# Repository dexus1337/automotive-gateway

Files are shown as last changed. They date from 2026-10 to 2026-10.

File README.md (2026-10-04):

# Automotive Gateway: Multi-Bus ECU Interface, MitM Filter & Telemetry Board


[]()
[]()
[]()

An automotive-grade, multi-protocol vehicle network interface, Man-in-the-Middle (MitM) filter, and wireless telemetry gateway. Rather than focusing on CAN alone, this board provides full hardware integration for **all three common automotive ECU communication methods**:
1. **High-Speed CAN (HS-CAN / CAN FD)**
2. **Fault-Tolerant Low-Speed CAN (FT-CAN)**
3. **K-Line / LIN (ISO 9141-2 / ISO 14230 / LIN 2.x)**

All three protocols are driven by two dedicated 32-bit ARM Cortex-M4 microcontrollers and an ESP32 wireless co-processor, featuring dual isolated channels per protocol.

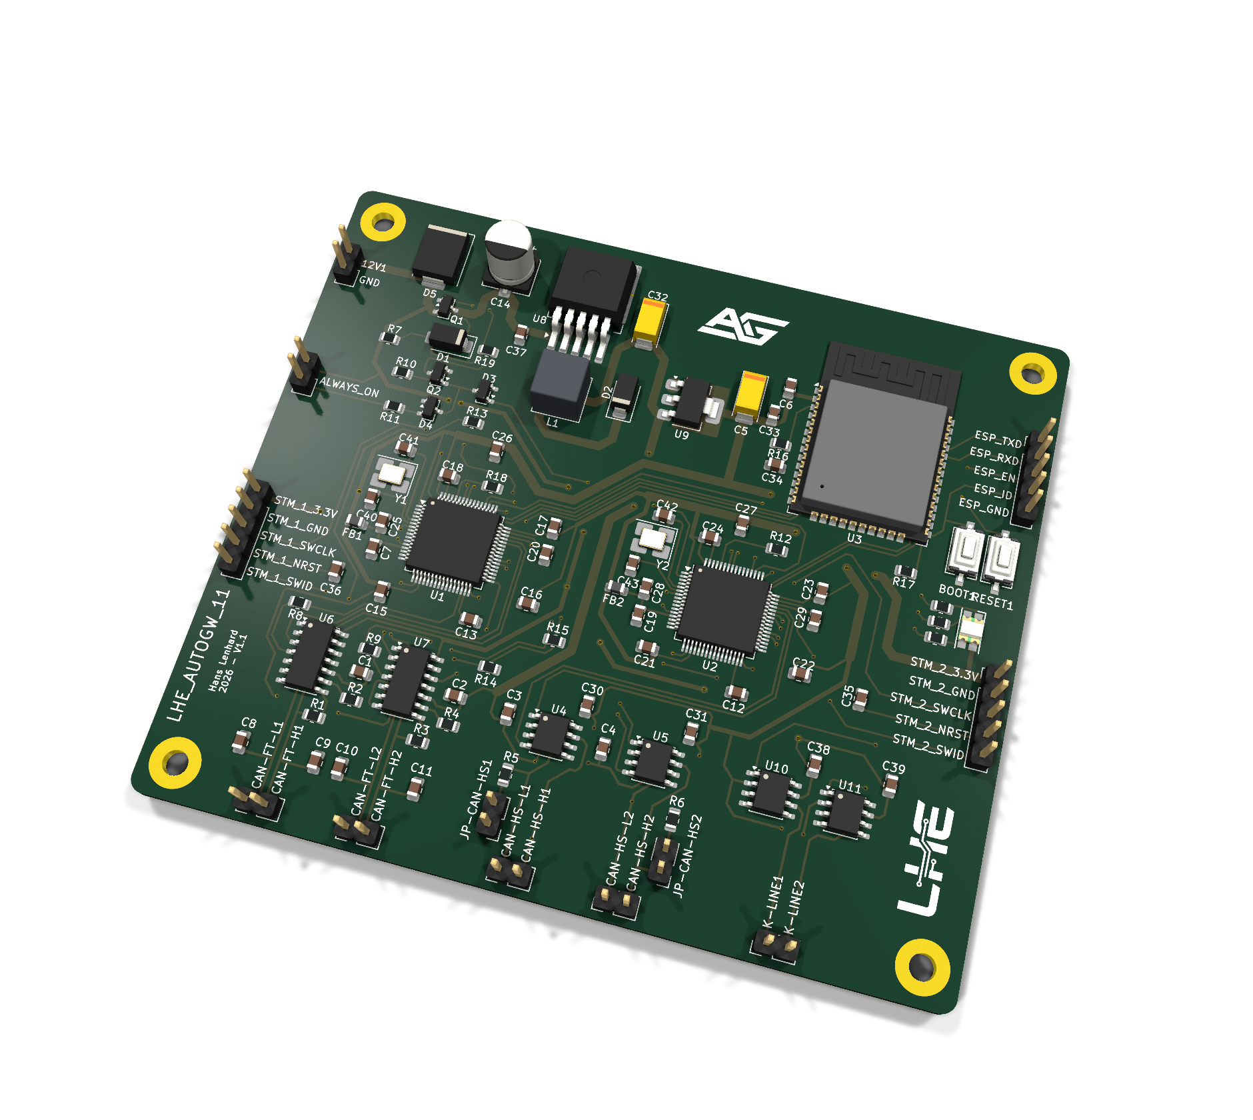
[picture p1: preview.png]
Automotive Multi-Bus Gateway PCB Preview


---

## 📑 Table of Contents

- [Overview](#-overview)
- [Operating Modes: Normal vs. MitM](#-operating-modes-normal-vs-mitm)
- [Power Management & Auto-Wake Architecture](#-power-management--auto-wake-architecture)
- [Key Features](#-key-features)
- [System Architecture](#-system-architecture)
- [Hardware & Functional Zones](#-hardware--functional-zones)
- [Pinout & Interface Definitions](#-pinout--interface-definitions)
- [Jumper Configuration Guide](#-jumper-configuration-guide)
- [Bill of Materials (BOM) Summary](#-bill-of-materials-bom-summary)
- [PCB Layout & Physical Specifications](#-pcb-layout--physical-specifications)
- [Getting Started & Flashing Guide](#-getting-started--flashing-guide)
- [Hardware Attribution](#-hardware-attribution)

---

## 🛠 Overview

Modern vehicle architectures rely on three primary communication standards to interconnect Electronic Control Units (ECUs) across various vehicle domains:
- **High-Speed CAN (HS-CAN / CAN FD)**: Up to 1 Mbps (CAN FD capable up to 5 Mbps) for latency-critical powertrain, drivetrain, braking, ABS, and chassis control.
- **Fault-Tolerant Low-Speed CAN (FT-CAN)**: Up to 125 kbps for robust body control, doors, lighting, climate (HVAC), and convenience systems, featuring automatic single-wire fallback upon bus faults.
- **K-Line / LIN (ISO 9141-2 / ISO 14230 / LIN 2.x)**: Bidirectional single-wire 12V automotive bus (up to 20 kbaud) universally used for OBD-II legacy diagnostics, ECU bench reflashing, instrumentation, and LIN sub-busses.

The **Automotive Gateway** provides a unified hardware platform equipped with dedicated transceivers for all three physical layers. It eliminates the need for separate diagnostic interfaces or multiple conversion dongles, serving as a comprehensive tool for active multi-bus communication, real-time message filtering, frame modification, diagnostic proxying, and wireless telemetry streaming via Wi-Fi and Bluetooth BLE.

---

## ⚙️ Operating Modes: Normal vs. MitM

The board features dual physical transceiver channels per communication method (Channel 1 and Channel 2), supporting two primary operating modes:

```
─────────────────────────────────────────────────────────────────────────────────────────────
 Mode 1: Normal Mode (Standalone Additional ECU / Gateway)
 [ Vehicle Network ] ◄──► ( Channel 1 ) ◄──► [ Dual-STM32 + ESP32 ] (Reads & Sends on Busses)

 Mode 2: In-line Man-in-the-Middle Mode (MitM Filter / Message Modification)
 [ Vehicle Network ] ◄──► ( Channel 1 ) ◄──► [ Real-Time Filter ] ◄──► ( Channel 2 ) ◄──► [ Target ECU ]
─────────────────────────────────────────────────────────────────────────────────────────────
```

### 1. Normal Mode (Standalone ECU)
> [!NOTE]
> **There is no listen-only mode.** In Normal Mode, the Automotive Gateway acts as an active, standalone, additional ECU on the vehicle networks.

- **Bi-directional Bus Access**: The gateway actively reads incoming data and transmits outgoing messages on the connected vehicle busses across all three supported physical interfaces (HS-CAN, FT-CAN, and K-Line/LIN).
- **Core Functions**:
  - Functions as an additional standalone ECU node directly participating on the network.
  - Broadcasts custom telemetry, control frames, or simulated sensor messages onto the bus.
  - Sends diagnostic requests (OBD-II, UDS / ISO 14229, KWP2000 / ISO 14230) to other vehicle ECUs and receives responses.
  - Acts as a bi-directional wireless gateway, streaming live multi-bus metrics and receiving remote commands over Wi-Fi (WebSockets, MQTT, REST) or Bluetooth LE.
- **Bus Connectivity**: Connects to the vehicle network via Channel 1 (`CAN-HS1`, `CAN-FT1`, and/or `K-LINE1 Pin 1`). Channel 2 can interface with a second independent vehicle bus, an auxiliary bench network, or remain unpopulated.

### 2. Man-in-the-Middle (MitM) Mode (In-line Filter & Message Modification)
- **Operation**: The gateway is inserted physically in-line between the vehicle wiring harness and a specific target Electronic Control Unit (ECU).
  - **Channel 1 (Network side)**: Connected to the main vehicle bus (`CAN-HS1`, `CAN-FT1`, or `K-LINE1 Pin 1`).
  - **Channel 2 (ECU side)**: Connected directly to the target ECU (`CAN-HS2`, `CAN-FT2`, or `K-LINE1 Pin 2`).
- **Core Functions**:
  - **Message Filtering**: Intercepts bidirectional communications in real time with sub-millisecond determinism to selectively filter out, block, or suppress unwanted messages, diagnostic requests, or forbidden IDs.
  - **Message Modification**: Inspects packets on the fly and modifies payload bytes, alters sensor values (e.g., vehicle speed, odometer, torque parameters), remaps frame IDs, recalculates CRCs/checksums, and retransmits them downstream.
  - **ECU Bench Testing & Security**: Allows fuzzing, spoofing responses, and security validation of a targeted ECU without injecting malformed or test frames into the rest of the vehicle.

---

## ⚡ Power Management & Auto-Wake Architecture

The board features an intelligent automotive power supply designed for both permanent vehicle installation and portable diagnostic use:

```
                        +12V Battery Input (12V1 Pin 1)
                                      │
                         [ D5: SMCJ24CA 24V TVS ]
                                      │
                         [ Q1: AO3401A P-MOSFET ]
                                      │ (12V_Switched)
                                      ▼
                        [ U8: LM2596S-5 Buck Conv ] ──► +5V Rail
                                      │
                        [ U9: AMS1117-3.3 LDO ]    ──► +3.3V Logic Rail
```

### Intelligent Sleep & Auto-Wake Circuit
To prevent 12V battery drain when permanently installed in a vehicle, the module features an ultra-low quiescent sleep circuit:
1. **Sleep State**: The high-side P-channel MOSFET (`Q1`) cuts +12V power to the buck converter (`U8`), completely disabling the 5V and 3.3V rails. The microcontrollers and ESP32 consume **zero current**.
2. **Wake-up Trigger**: The Fault-Tolerant CAN transceiver (`U6`, NXP TJA1055T) remains powered directly from the protected 12V battery rail in ultra-low quiescent standby mode. Upon detecting bus activity on FT-CAN Channel 1, `U6` asserts its `INH` pin HIGH, pulling the gate of N-channel MOSFET `Q2` high via dual Schottky diode `D4`.
3. **Power Latch (Keep-Alive)**: `Q2` activates, pulling `Q1`'s gate low to turn ON the system power rails. Once booted, MCU 1 (`U1`) and MCU 2 (`U2`) assert their respective keep-alive GPIOs (`PC13` via `D3`) to latch power continuously.
4. **Controlled Shutdown**: When vehicle network traffic ceases, the firmware prepares for safe shutdown and de-asserts `PC13`, allowing the board to return to sleep.
5. **Always-On Override (`J3`)**: Installing a jumper on header `J3` (`JP_ALWAYS_ON`) bypasses the auto-wake logic and holds the board permanently powered whenever +12V is present.

---

## ✨ Key Features

- **Dual ARM Cortex-M4 Processing Core**:
  - Two dedicated **STM32F405RGTx** microcontrollers running at **168 MHz** (1 MB Flash, 192 KB SRAM each).
  - **MCU 1 (`U1`)**: Dedicated Low-Speed Fault-Tolerant CAN controller (`CAN1` & `CAN2`).
  - **MCU 2 (`U2`)**: Dedicated High-Speed CAN (`CAN1` & `CAN2`) and Dual K-Line controller (`USART1` & `USART6`).
- **Direct High-Speed Inter-MCU Link**:
  - Dedicated hardware UART bus connecting MCU 1 and MCU 2 (`PC10` / `PC11`) for deterministic cross-bus message passing without co-processor latency.
- **All 3 Common Automotive ECU Physical Layers Supported (Dual Channels Each)**:
  - **High-Speed CAN (HS-CAN / CAN FD)**: 2× NXP `TJA1044GT-3` transceivers (ISO 11898-2:2016, CAN FD ready up to 5 Mbps) with switchable 120 Ω bus termination.
  - **Fault-Tolerant Low-Speed CAN (FT-CAN)**: 2× NXP `TJA1055T/3` transceivers (ISO 11898-3, up to 125 kbps) with single-wire fallback and automatic wake-up signaling.
  - **Dual K-Line / LIN (ISO 9141-2 / ISO 14230 / LIN 2.x)**: 2× NXP `TJA1021xT` transceivers (LIN 2.2A / SAE J2602) supporting OBD-II and KWP2000 diagnostic lines up to 20 kbaud.
- **High-Precision External Quartz Clocking (HSE)**:
  - Dedicated 8.000 MHz SMD-3225 4-pin quartz crystals (`Y1`, `Y2`) with 15 pF C0G load capacitors (`C40`–`C43`) for both STM32F405 MCUs.
  - Automotive-grade $\pm 10\,\text{ppm}$ clock accuracy, eliminating internal RC oscillator frequency drift across automotive temperature ranges.
  - **Zero-Error Baud Rate Timing**: Derives an exact 42 MHz APB1 peripheral clock, achieving $0.000\%$ timing error for the critical **83.3333 kBd** Fault-Tolerant CAN standard ($\text{BRP}=28$, $18\,T_q$, $83.33\%$ sample point) as well as exact bit rates for 100k, 125k, 250k, 500k, and 1 MBd HS-CAN / CAN FD.
- **Wireless Telemetry Co-Processor**:
  - **ESP32-WROOM-32UE** module with 2.4 GHz Wi-Fi (802.11 b/g/n) and Bluetooth v4.2 BR/EDR & BLE.
  - Integrated U.FL external antenna connector for high-gain antenna placement inside vehicle dashboards or engine bays.
  - Dual independent high-speed UART links connecting to MCU 1 and MCU 2.
- **User Interface & Diagnostic Feedback**:
  - Onboard RGB Status LED (`D6`, SMD 1210) driven by ESP32 GPIOs for mode, packet activity, and error signaling.
  - Tactile push buttons for ESP32 hardware `RESET` and `BOOT` (GPIO0).
- **Automotive Protection & Regulation**:
  - Automotive transient voltage suppressor (`D5`, SMCJ24CA bidirectional TVS).
  - P-channel MOSFET (`Q1`, AO3401A) reverse polarity and high-side power switching.
  - 12V Zener (`D1`, MMSZ12T1G) Vgs gate overvoltage clamp.
  - High-efficiency switching buck regulator (`U8`, LM2596S-5, 3A capacity).
  - Low-dropout linear regulator (`U9`, AMS1117-3.3, 1A capacity).
  - Ferrite bead filtering (`FB1`, `FB2`) on analog power supplies (`VDDA`).

---

## 📐 System Architecture

```
                                  +12V AUTOMOTIVE BATTERY (12V1)
                                                │
                          ┌─────────────────────┴─────────────────────┐
                          ▼                                           ▼
             [ SMCJ24CA 24V TVS Clamp ]                  [ AO3401A P-MOSFET Switch ]
                          │                                           │ (12V_Switched)
                          │                                           ▼
                          │                              [ LM2596S-5 Buck Regulator ] ──► +5V Rail
                          │                                           │
                          │                              [ AMS1117-3.3 LDO Regulator] ──► +3.3V Rail
                          │                                           │
         ┌────────────────┴───────────────────────────────────────────┴────────────────────────┐
         │                                                            │                        │
         ▼                                                            ▼                        ▼
┌───────────────────────────────┐               ┌───────────────────────────────┐   ┌──────────────────────┐
│      STM32F405 #1 (MCU 1)     │               │      STM32F405 #2 (MCU 2)     │   │   ESP32-WROOM-32UE   │
│   Low-Speed Fault-Tolerant    │◄─────────────►│     High-Speed CAN & K-Line   │   │   Wireless Gateway   │
│   CAN Controller (168 MHz)    │  Direct UART  │     Controller (168 MHz)      │   │   (Wi-Fi / BT / BLE) │
└──────┬─────────────────┬──────┘   (PC10/PC11) └──────┬─────────────────┬──────┘   └───────┬──────┬───────┘
       │ (CAN1)          │ (CAN2)                      │ (CAN1)          │ (CAN2)           │      │
       ▼                 ▼                             ▼                 ▼                  │      │
 ┌───────────┐     ┌───────────┐                 ┌───────────┐     ┌───────────┐            │      │
 │  TJA1055T │     │  TJA1055T │                 │ TJA1044GT │     │ TJA1044GT │      UART1 │      │ UART2
 │ (FT-CAN1) │     │ (FT-CAN2) │                 │ (HS-CAN1) │     │ (HS-CAN2) │   (PA2/PA3)│      │(PA2/PA3)
 └─────┬─────┘     └─────┬─────┘                 └─────┬─────┘     └─────┬─────┘            │      │
       │                 │                             │                 │                  │      │
       ▼                 ▼                             ▼                 ▼                  │      │
 [  CAN-FT1  ]     [  CAN-FT2  ]                 [  CAN-HS1  ]     [  CAN-HS2  ]            ▼      ▼
 (Channel 1)       (Channel 2)                   (Channel 1)       (Channel 2)          [ Independent ]
  Normal / MitM     Normal / MitM                 Normal / MitM     Normal / MitM       [ UART Links  ]
                                                       │                 │                     │
                                                 ┌─────┴─────┐     ┌─────┴─────┐               ▼
                                                 │JP-CAN-HS1 │     │JP-CAN-HS2 │        [ RGB LED (D6) ]
                                                 │(120Ω Term)│     │(120Ω Term)│        [ GPIO25/26/27 ]
                                                 └───────────┘     └───────────┘
                                                
                                                [ MCU 2 UARTs (USART6 / USART1) ]
                                                               │
                                                   ┌───────────┴───────────┐
                                                   ▼                       ▼
                                             ┌───────────┐           ┌───────────┐
                                             │ TJA1021xT │           │ TJA1021xT │
                                             │ (K-Line 1)│           │ (K-Line 2)│
                                             └─────┬─────┘           └─────┬─────┘
                                                   │                       │
                                                   ▼                       ▼
                                             [        K-LINE1 Header       ]
                                             [  Pin 1: Ch 1  |  Pin 2: Ch 2]
                                             [         Normal / MitM       ]
```

---

## 🔍 Hardware & Functional Zones

### Zone 1: Power Regulation, Switching & Protection
- **Power Input**: Connector `12V1` (Pin 1: `+12V_Protected`, Pin 2: `GND`).
- **Protection**:
  - `D5` (`SMCJ24CA`): Bidirectional TVS diode clamps automotive load-dump surges.
  - `Q1` (`AO3401A`): P-channel MOSFET provides high-side switching and reverse-polarity protection.
  - `D1` (`MMSZ12T1G`): 12V Zener clamps gate-source voltage ($V_{GS}$) of `Q1`.
  - `D2` (`SS34`): 3A 40V Schottky barrier rectifier for the buck switching regulator.
- **Power Switching Logic**:
  - `Q2` (`2N7002`): N-channel MOSFET drives `Q1`'s gate low to enable system power.
  - `D4` (`BAT54C`): Dual diode ORs the auto-wake signal from `U6` (`INH`) and `J3` (`ALWAYS_ON`).
  - `D3` (`BAT54C`): Dual diode ORs keep-alive latch signals from MCU 1 (`U1 PC13`) and MCU 2 (`U2 PC13`).
- **Regulators**:
  - `U8` (`LM2596S-5`): High-efficiency 5V 3A step-down switching regulator.
  - `U9` (`AMS1117-3.3`): 3.3V 1A linear LDO regulator for logic and radio power.

### Zone 2: MCU #1 – Low-Speed Fault-Tolerant CAN Core
- **Microcontroller**: `U1` (`STM32F405RGTx` LQFP-64, ARM Cortex-M4 @ 168 MHz).
- **External Clock Source**: `Y1` (8.000 MHz SMD-3225 4-pin crystal on `PH0-OSC_IN` [Pin 5] and `PH1-OSC_OUT` [Pin 6]) with 15 pF load capacitors `C40` & `C41`.
- **Transceivers**: `U6` & `U7` (`NXP TJA1055T/3` SOIC-14).
- **Pin Mapping**:
  - `FT-CAN 1` (Channel 1): RX = `PA11`, TX = `PA12`, Wake Inhibit = `U6 INH`, Error = `U6 ~ERR` (`PB11` via `R8`), Standby = `PC7`, Enable = `PC8`.
  - `FT-CAN 2` (Channel 2): RX = `PB5`, TX = `PB6`, Error = `U7 ~ERR` (`PB12` via `R9`), Standby/Enable = Tied to 3.3V.
  - Power Keep-Alive: `PC13` (controls `Q2` gate via `D3`).
  - Inter-MCU Link: TX = `PC10`, RX = `PC11` (connects directly to MCU 2).
  - ESP32 Link: TX = `PA2`, RX = `PA3` (connects to ESP32 `IO19` / `IO18`).
  - SWD Debug: SWCLK = `PA14`, SWDIO = `PA13`, NRST = `Pin 7`.

### Zone 3: MCU #2 – High-Speed CAN & Dual K-Line Core
- **Microcontroller**: `U2` (`STM32F405RGTx` LQFP-64, ARM Cortex-M4 @ 168 MHz).
- **External Clock Source**: `Y2` (8.000 MHz SMD-3225 4-pin crystal on `PH0-OSC_IN` [Pin 5] and `PH1-OSC_OUT` [Pin 6]) with 15 pF load capacitors `C42` & `C43`.
- **High-Speed Transceivers**: `U4` & `U5` (`NXP TJA1044GT-3` SOIC-8).
- **K-Line Transceivers**: `U10` & `U11` (`NXP TJA1021xT` SOIC-8).
- **Pin Mapping**:
  - `HS-CAN 1` (Channel 1): RX = `PA11`, TX = `PA12`.
  - `HS-CAN 2` (Channel 2): RX = `PB5`, TX = `PB6`.
  - `K-Line 1` (Channel 1, `U10`): TX = `PC6` (`USART6_TX`), RX = `PC7` (`USART6_RX`).
  - `K-Line 2` (Channel 2, `U11`): TX = `PA9` (`USART1_TX`), RX = `PA10` (`USART1_RX`).
  - Power Keep-Alive: `PC13` (controls `Q2` gate via `D3`).
  - Inter-MCU Link: TX = `PC10`, RX = `PC11` (connects directly to MCU 1).
  - ESP32 Link: TX = `PA2`, RX = `PA3` (connects to ESP32 `IO17` / `IO16`).
  - SWD Debug: SWCLK = `PA14`, SWDIO = `PA13`, NRST = `Pin 7`.

### Zone 4: ESP32 Wireless Telemetry Co-Processor
- **Module**: `U3` (`ESP32-WROOM-32UE` with external U.FL antenna jack).
- **Pin Mapping**:
  - Link to MCU 1: RX = `IO19`, TX = `IO18`.
  - Link to MCU 2: RX = `IO16`, TX = `IO17`.
  - Programming Port: `TXD0` (`Pin 35`), `RXD0` (`Pin 34`), `EN` (`Pin 3`), `IO0` (`Pin 25`).
  - RGB Status LED (`D6`): Red = `IO25`, Green = `IO26`, Blue = `IO27`.
  - Hardware Buttons: `RESET` (pulls `EN` low), `BOOT` (pulls `IO0` low).

---

## 🔌 Pinout & Interface Definitions

All external signals, power, bus lines, and programming ports are brought out to standardized 2.54 mm pin headers:

### 1. Automotive Power Header (`12V1`)
| Pin | Silkscreen | Net Name | Voltage Range | Description |
| :---: | :--- | :--- | :--- | :--- |
| **1** | *(Square pad)* | `/12V_Protected` | +7.0V to +18.0V DC | Primary Automotive Battery/Ignition Supply |
| **2** | `GND` | `/GND` | 0V | Common Chassis / System Ground |

### 2. High-Speed CAN Connectors
| Connector | Pin | Silkscreen | Signal | Transceiver Pin | Function / Topology |
| :--- | :---: | :--- | :--- | :--- | :--- |
| **`CAN-HS1`** | 1 | `CAN-HS-L1` | `CAN_L` | `U4` Pin 6 | **Channel 1**: Normal Mode (Vehicle Bus) / MitM Input |
| | 2 | `CAN-HS-H1` | `CAN_H` | `U4` Pin 7 | **Channel 1**: Normal Mode (Vehicle Bus) / MitM Input |
| **`CAN-HS2`** | 1 | `CAN-HS-L2` | `CAN_L` | `U5` Pin 6 | **Channel 2**: MitM Output (Target ECU) / Secondary Bus |
| | 2 | `CAN-HS-H2` | `CAN_H` | `U5` Pin 7 | **Channel 2**: MitM Output (Target ECU) / Secondary Bus |

### 3. Fault-Tolerant Low-Speed CAN Connectors
| Connector | Pin | Silkscreen | Signal | Transceiver Pin | Function / Topology |
| :--- | :---: | :--- | :--- | :--- | :--- |
| **`CAN-FT1`** | 1 | `CAN-FT-L1` | `CAN_L` | `U6` Pin 12 | **Channel 1**: Normal Mode (Vehicle Bus) / MitM Input / Auto-Wake |
| | 2 | `CAN-FT-H1` | `CAN_H` | `U6` Pin 11 | **Channel 1**: Normal Mode (Vehicle Bus) / MitM Input / Auto-Wake |
| **`CAN-FT2`** | 1 | `CAN-FT-L2` | `CAN_L` | `U7` Pin 12 | **Channel 2**: MitM Output (Target ECU) / Secondary Bus |
| | 2 | `CAN-FT-H2` | `CAN_H` | `U7` Pin 11 | **Channel 2**: MitM Output (Target ECU) / Secondary Bus |

### 4. Dual K-Line / LIN Connector (`K-LINE1`)
| Pin | Silkscreen | Connected Transceiver | MCU Peripheral | Operating Voltage | Function / Topology |
| :---: | :--- | :--- | :--- | :---: | :--- |
| **1** | *(Pin 1)* | `U10` (TJA1021xT Pin 6) | MCU 2 `USART6` (`PC6`/`PC7`) | 12V Automotive | **Channel 1**: Normal Mode (OBD-II / Harness) / MitM Input |
| **2** | `K-LINE2` | `U11` (TJA1021xT Pin 6) | MCU 2 `USART1` (`PA9`/`PA10`)| 12V Automotive | **Channel 2**: MitM Output (Target ECU) / Secondary K-Line |

### 5. Programming & SWD Debug Headers
| Header | Pin 1 | Pin 2 | Pin 3 | Pin 4 | Pin 5 | Target IC |
| :--- | :---: | :---: | :---: | :---: | :---: | :--- |
| **`STM_FLASH1`** | `+3.3V` | `GND` | `SWDIO` (`PA13`) | `NRST` | `SWCLK` (`PA14`) | MCU 1 (STM32F405 FT-CAN Core) |
| **`STM_FLASH2`** | `+3.3V` | `GND` | `SWDIO` (`PA13`) | `NRST` | `SWCLK` (`PA14`) | MCU 2 (STM32F405 HS-CAN & K-Line Core) |
| **`ESP_FLASH1`** | `TXD0` | `RXD0` | `ESP_EN` | `GPIO0 (BOOT)` | `GND` | ESP32-WROOM-32UE Wireless Co-Processor |

---

## 🎛 Jumper Configuration Guide

| Jumper Header | Silkscreen | Function | Jumper Installed (Closed) | Jumper Removed (Open) | Default |
| :--- | :--- | :--- | :--- | :--- | :---: |
| **`J3`** | `ALWAYS_ON` | Power Control Mode | **Always-On**: Board powered whenever 12V is connected. | **Auto-Sleep / Wake**: Board sleeps; wakes on FT-CAN activity. | *Open* |
| **`JP-CAN-HS1`** | *(Near CAN-HS1)* | HS-CAN 1 Bus Termination | **120 Ω Enabled** (`R5` connected across H and L). | **Unterminated** (For active vehicle bus connection). | *Open* |
| **`JP-CAN-HS2`** | *(Near CAN-HS2)* | HS-CAN 2 Bus Termination | **120 Ω Enabled** (`R6` connected across H and L). | **Unterminated** (For active vehicle bus connection). | *Open* |

> [!TIP]
> - In **Normal Mode** connected to an active vehicle network, keep `JP-CAN-HS1` and `JP-CAN-HS2` **OPEN** because the vehicle network already provides the required split 60 Ω termination.
> - In **MitM Mode** or bench-testing an isolated ECU, install the jumper on the isolated segment (`JP-CAN-HS2`) to provide the required 120 Ω termination for CAN transceivers.

---

## 📦 Bill of Materials (BOM) Summary

| Reference Designator | Component Value | Package / Footprint | Qty | Description |
| :--- | :--- | :--- | :---: | :--- |
| **`U1`, `U2`** | `STM32F405RGTx` | LQFP-64 (10×10 mm, 0.5 mm pitch) | 2 | 32-bit ARM Cortex-M4 MCU (168 MHz, 1MB Flash, 192KB RAM) |
| **`U3`** | `ESP32-WROOM-32UE` | RF Module (18×25.5 mm) | 1 | Dual-Core Wi-Fi & BLE Co-Processor (U.FL antenna) |
| **`U4`, `U5`** | `TJA1044GT-3` | SOIC-8 (3.9×4.9 mm, 1.27 mm pitch) | 2 | High-Speed CAN Transceiver (CAN FD capable, 5 Mbps) |
| **`U6`, `U7`** | `TJA1055T/3` | SOIC-14 (3.9×8.7 mm, 1.27 mm pitch) | 2 | Fault-Tolerant Low-Speed CAN Transceiver (125 kbps) |
| **`U10`, `U11`** | `TJA1021xT` | SOIC-8 (3.9×4.9 mm, 1.27 mm pitch) | 2 | LIN 2.2A / K-Line Physical Transceiver (ISO 9141-2) |
| **`U8`** | `LM2596S-5` | TO-263-5 (D2PAK) | 1 | 5V 3A Step-Down Switching Buck Regulator |
| **`U9`** | `AMS1117-3.3` | SOT-223-3 | 1 | 3.3V 1A Low-Dropout Linear Regulator |
| **`Q1`** | `AO3401A` | SOT-23 | 1 | P-Channel MOSFET (-30V, -4.2A, Power Switch / Rev. Pol.) |
| **`Q2`** | `2N7002` | SOT-23 | 1 | N-Channel Signal MOSFET (60V, 115mA, Gate Driver) |
| **`D1`** | `MMSZ12T1G` | SOD-123 / SMA | 1 | 12V 500mW Zener Diode (MOSFET Vgs Clamp) |
| **`D2`** | `SS34` | DO-214AC (SMA) | 1 | 3A 40V Schottky Barrier Rectifier Diode |
| **`D3`, `D4`** | `BAT54C` | SOT-23 | 2 | Dual Common-Cathode 30V Schottky Diodes |
| **`D5`** | `SMCJ24CA` | DO-214AB (SMC) | 1 | 24V 1500W Bidirectional TVS Surge Clamping Diode |
| **`D6`** | `LED_RGBA` | SMD 1210 (Common Anode) | 1 | RGB Status & Diagnostic Indicator LED |
| **`L1`** | `33-68 µH` | Bourns SRP6060FA (SMD Inductor) | 1 | Power Inductor for LM2596 Buck Converter |
| **`FB1`, `FB2`** | `Ferrite Bead` | SMD 0805 | 2 | High-Frequency Analog Noise Filtering Beads (`VDDA`) |
| **`Y1`, `Y2`** | `8.000 MHz` | SMD-3225 4-Pin (HandSoldering) | 2 | High-Precision HSE Quartz Crystals (±10 ppm, 15 pF CL) |
| **`RESET`, `BOOT`** | `PTS636Sx25` | Tactile Switch SMD | 2 | Push buttons for ESP32 Hardware Reset & Boot Mode |
| **`R5`, `R6`** | `120 Ω` | SMD 0805 (1%) | 2 | High-Speed CAN Bus Termination Resistors |
| **`R1` - `R4`** | `560 Ω` | SMD 0805 (1%) | 4 | Fault-Tolerant CAN Bias/Termination Resistors |
| **`R20` - `R22`** | `1 kΩ` | SMD 0805 | 3 | RGB LED Current Limiting Resistors |
| **`R7`, `R13`** | `100 kΩ` | SMD 0805 | 2 | Gate & Inhibit Pull-Down Resistors |
| **`R8` - `R12`, `R14` - `R19`** | `10 kΩ` | SMD 0805 | 11 | Pull-Up / Pull-Down / Logic Bias Resistors |
| **`C14`** | `100 µF` | SMD Aluminum Electrolytic (6.3×7.7 mm)| 1 | 12V Switched Input Decoupling |
| **`C5`, `C32`** | `220 µF` | EIA-6032-28 (Kemet C Tantalum) | 2 | 5V and 3.3V Output Smoothing Capacitors |
| **`C8` - `C11`** | `5.6 nF` | SMD 0805 | 4 | FT-CAN Bus Filter Capacitors |
| **`C12`, `C13`, `C20`, `C29`** | `2.2 µF` | SMD 0805 | 4 | MCU VCAP Core Decoupling Capacitors |
| **`C26`, `C27`** | `4.7 µF` | SMD 0805 | 2 | Power Rail Filtering Capacitors |
| **`C25`, `C28`, `C34`** | `1 µF` | SMD 0805 | 3 | Logic Decoupling Capacitors |
| **`C1` - `C4`, `C6`, `C7`, `C15` - `C19`, `C21` - `C24`, `C30`, `C31`, `C33`, `C35` - `C39` | `100 nF` | SMD 0805 | 22 | Local IC Decoupling Ceramic Capacitors |
| **`C40` - `C43`** | `15 pF` | SMD 0805 (C0G/NP0) | 4 | Crystal Load Capacitors (HSE Oscillators) |
| **`12V1`, `J3`, `CAN-HS1/2`, `CAN-FT1/2`, `JP-CAN-HS1/2`, `K-LINE1`** | `Conn_01x02_Pin` | 2.54 mm Pin Header (1×02) | 8 | External Power, Bus & Termination Headers |
| **`STM_FLASH1`, `STM_FLASH2`, `ESP_FLASH1`** | `Conn_01x05_Pin` | 2.54 mm Pin Header (1×05) | 3 | Programming and SWD Debug Headers |
| **`H1` - `H4`** | `MountingHole_Pad` | 3.2 mm Diameter (M3 Pad) | 4 | Grounded Chassis M3 Mounting Holes |

---

## 📏 PCB Layout & Physical Specifications

- **Dimensions**: **101.60 mm × 88.90 mm** (4.00" × 3.50")
- **Corner Fillet**: 2.0 mm corner radius
- **Layer Count**: **2 Copper Layers** (`F.Cu` Top Layer, `B.Cu` Bottom Layer)
- **Board Thickness**: Standard 1.6 mm FR4
- **Copper Thickness**: 1 oz (35 µm)
- **Ground Planes**: Continuous, low-impedance ground fill on the bottom layer with stitched return paths for high-frequency CAN differential lines.
- **Mounting**: 4× grounded M3 mounting holes located at the corners.
- **Footprint Pitch**: Standard 0805 (2012 metric) passive SMD footprints for reliable hand-soldering and prototype assembly.
- **Total Footprint Count**: 109 placed board footprints.

---

## 🚀 Getting Started & Flashing Guide

### 1. Opening the KiCad Project
1. Install **KiCad 8.0** or newer.
2. Clone the repository:
   ```bash
   git clone https://github.com/dexus1337/automotive-gateway.git
   ```
3. Open `automotive-gateway.kicad_pro` to inspect or modify schematics and PCB layout.

### 2. Flashing STM32 Microcontrollers (MCU 1 & MCU 2)
The board features independent 5-pin SWD headers for each STM32F405 MCU:
- **MCU 1 (Low-Speed FT-CAN Core)**: Connect an ST-LINK V2/V3 to `STM_FLASH1` (`3.3V`, `GND`, `SWDIO`, `NRST`, `SWCLK`).
- **MCU 2 (High-Speed CAN & K-Line Core)**: Connect an ST-LINK to `STM_FLASH2` (`3.3V`, `GND`, `SWDIO`, `NRST`, `SWCLK`).
- Compatible toolchains: **STM32CubeIDE**, **PlatformIO** (`ststm32`), or **Keil MDK**.

### 3. Flashing the ESP32 Wireless Co-Processor
1. Connect a 3.3V USB-to-UART adapter to `ESP_FLASH1`:
   - Adapter TX ──► `ESP_RXD` (Pin 2)
   - Adapter RX ──► `ESP_TXD` (Pin 1)
   - Adapter GND ──► `ESP_GND` (Pin 5)
2. Enter Bootloader Mode:
   - Hold down the **`BOOT`** button.
   - Press and release the **`RESET`** button.
   - Release the **`BOOT`** button.
3. Flash using **ESP-IDF**, **esptool.py**, or **PlatformIO** (`espressif32`).

---

## 👤 Hardware Attribution

- **Hardware Design & Engineering**: Hans Lenhard
- **Hardware Revision**: V1.1 (2026)
- **Silkscreen Identification**: `LHE_AUTOGW_11`

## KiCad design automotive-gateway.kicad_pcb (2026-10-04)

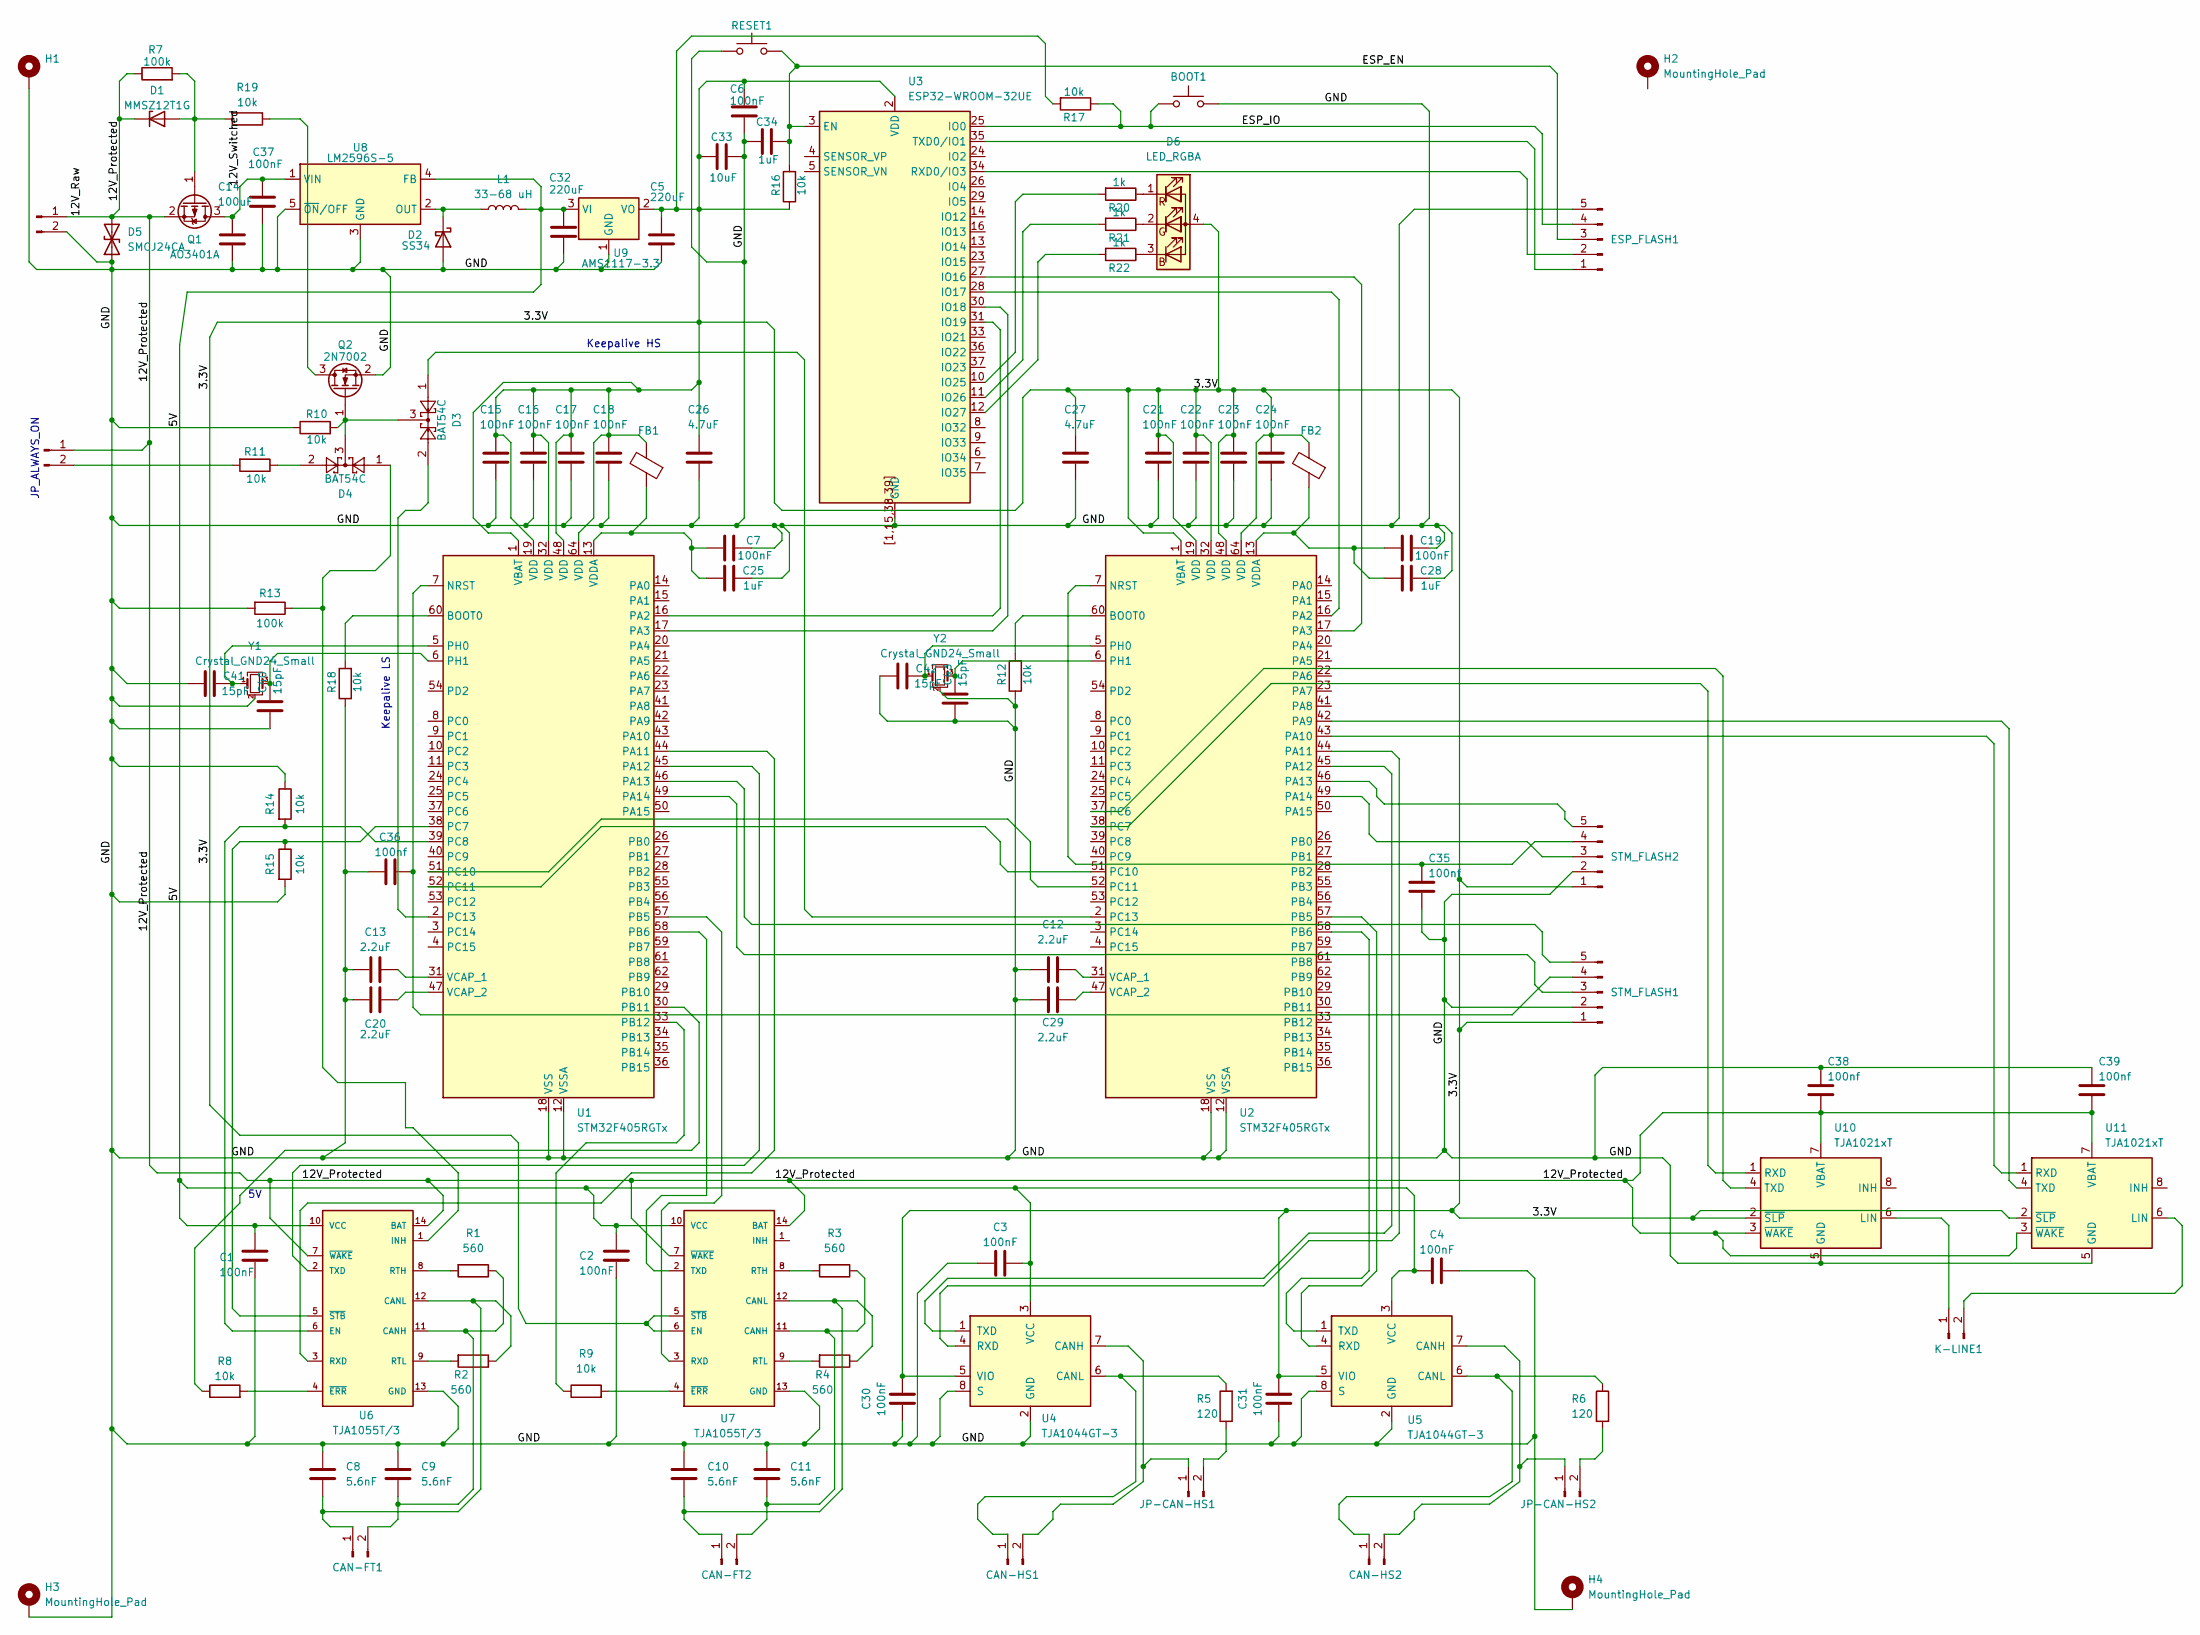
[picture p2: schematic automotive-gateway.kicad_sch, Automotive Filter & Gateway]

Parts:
12V1: Conn_01x02_Pin; PinHeader_1x02_P2.54mm_Vertical
BOOT1: ESP_BOOT; SW_Tactile_SPST_NO_Straight_CK_PTS636Sx25SMTRLFS
C1, C2, C3, C4, C6, C7, C15, C16, C17, C18, C19, C21, C22, C23, C24, C30, C31, C37: 100nF; C_0805_2012Metric
C5, C32: 220uF; CP_EIA-6032-28_Kemet-C_HandSolder
C8, C9, C10, C11: 5.6nF; C_0805_2012Metric
C12, C13, C20, C29: 2.2uF; C_0805_2012Metric
C14: 100uF; CP_Elec_6.3x7.7
C25, C28, C34: 1uF; C_0805_2012Metric
C26, C27: 4.7uF; C_0805_2012Metric
C33: 10uF; C_0805_2012Metric
C35, C36, C38, C39: 100nf; C_0805_2012Metric
C40, C41, C42, C43: 15pF; C_0805_2012Metric
CAN-FT1, CAN-FT2: Conn_01x02_Pin; PinHeader_1x02_P2.54mm_Vertical
CAN-HS1, CAN-HS2: Conn_01x02_Pin; PinHeader_1x02_P2.54mm_Vertical
D1: MMSZ12T1G; D_SMA
D2: SS34; D_SMA
D3, D4: BAT54C; SOT-23
D5: SMCJ24CA; D_SMC
D6: LED_RGBA; LED_RGB_1210
ESP_FLASH1: Conn_01x05_Pin; PinHeader_1x05_P2.54mm_Vertical
FB1, FB2: L_0805_2012Metric
H1, H2, H3, H4: MountingHole_Pad; MountingHole_3.2mm_M3_Pad
J3: Conn_01x02_Pin; PinHeader_1x02_P2.54mm_Vertical
JP-CAN-HS1, JP-CAN-HS2: Conn_01x02_Pin; PinHeader_1x02_P2.54mm_Vertical
K-LINE1: Conn_01x02_Pin; PinHeader_1x02_P2.54mm_Vertical
L1: 33-68 uH; L_Bourns_SRP6060FA
Q1: AO3401A; SOT-23
Q2: 2N7002; SOT-23
R1, R2, R3, R4: 560; R_0805_2012Metric
R5, R6: 120; R_0805_2012Metric
R7, R13: 100k; R_0805_2012Metric
R8, R9, R10, R11, R12, R14, R15, R16, R17, R18, R19: 10k; R_0805_2012Metric
R20, R21, R22: 1k; R_0805_2012Metric
RESET1: ESP_RESET; SW_Tactile_SPST_NO_Straight_CK_PTS636Sx25SMTRLFS
STM_FLASH1, STM_FLASH2: Conn_01x05_Pin; PinHeader_1x05_P2.54mm_Vertical
U1, U2: STM32F405RGTx; LQFP-64_10x10mm_P0.5mm
U3: ESP32-WROOM-32UE; ESP32-WROOM-32E
U4, U5: TJA1044GT-3; SOIC-8_3.9x4.9mm_P1.27mm
U6, U7: TJA1055T/3; SOIC-14_3.9x8.7mm_P1.27mm
U8: LM2596S-5; TO-263-5_TabPin3
U9: AMS1117-3.3; SOT-223-3_TabPin2
U10, U11: TJA1021xT; SOIC-8_3.9x4.9mm_P1.27mm
Y1, Y2: Crystal_GND24_Small; Crystal_SMD_3225-4Pin_3.2x2.5mm_HandSoldering

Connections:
/3.3V: C5.2, C6.1, C15.1, C16.1, C17.1, C18.1, C21.1, C22.1, C23.1, C24.1, C26.1, C27.1, C30.1, C31.1, C33.1, D6.4 (A), FB1.2, FB2.2, R16.1, R17.2, STM_FLASH1.1, STM_FLASH2.1, U1.1 (VBAT), U1.19 (VDD), U1.32 (VDD), U1.48 (VDD), U1.64 (VDD), U2.1 (VBAT), U2.19 (VDD), U2.32 (VDD), U2.48 (VDD), U2.64 (VDD), U3.2 (VDD), U4.5 (VIO), U5.5 (VIO), U7.5 (~STB), U7.6 (EN), U9.2 (VO), U10.2 (~SLP), U11.2 (~SLP)
/5V: C1.2, C2.2, C3.1, C4.2, C32.2, L1.2, U4.3 (VCC), U5.3 (VCC), U6.10 (VCC), U7.10 (VCC), U8.4 (FB), U9.3 (VI)
/12V_Protected: 12V1.1, C38.1, C39.1, D1.1 (K), D5.2 (A2), J3.1, Q1.2 (S), R7.1, U6.7 (~WAKE), U6.14 (BAT), U7.7 (~WAKE), U7.14 (BAT), U10.3 (~WAKE), U10.7 (VBAT), U11.3 (~WAKE), U11.7 (VBAT)
/12V_Switched: C14.2, C37.2, Q1.3 (D), U8.1 (VIN)
/ESP_EN: C34.1, ESP_FLASH1.3, R16.2, RESET1.2, U3.3 (EN); also elsewhere on the board
/ESP_IO: BOOT1.1, ESP_FLASH1.4, R17.1, U3.25 (IO0); also elsewhere on the board
/GND: 12V1.2, BOOT1.2, C1.1, C2.1, C3.2, C4.1, C5.1, C6.2, C7.2, C8.2, C9.2, C10.2, C11.2, C12.1, C13.1, C14.1, C15.2, C16.2, C17.2, C18.2, C19.2, C20.1, C21.2, C22.2, C23.2, C24.2, C25.2, C26.2, C27.2, C28.2, C29.1, C30.2, C31.2, C32.1, C33.2, C34.2, C35.1, C36.2, C37.1, C38.2, C39.2, C40.1, C41.1, C42.1, C43.1, D2.2 (A), D5.1 (A1), ESP_FLASH1.5, H1.1 (1_1), H3.1 (1_1), H4.1 (1_1), Q2.2 (S), R10.1, R12.1, R13.2, R14.1, R15.2, R18.1, RESET1.1, STM_FLASH1.2, STM_FLASH2.2, U1.12 (VSSA), U1.18 (VSS), U1.63 (VSS), U2.12 (VSSA), U2.18 (VSS), U2.63 (VSS), U3.1 (GND), U3.15 (GND), U3.38 (GND), U3.39 (GND), U3.[1,15,38,39] (GND), U4.2 (GND), U4.8 (S), U5.2 (GND), U5.8 (S), U6.13 (GND), U7.13 (GND), U8.3 (GND), U8.5 (~ON/OFF), U9.1 (GND), U10.5 (GND), U11.5 (GND), Y1.2 (G), Y1.4 (G), Y2.2 (G), Y2.4 (G); also elsewhere on the board
unnamed: C8.1, CAN-FT1.1, R2.1, U6.12 (CANL)
unnamed: C9.1, CAN-FT1.2, R1.1, U6.11 (CANH)
unnamed: C10.1, CAN-FT2.1, R4.1, U7.12 (CANL)
unnamed: C11.1, CAN-FT2.2, R3.1, U7.11 (CANH)
unnamed: CAN-HS1.1, R5.2, U4.6 (CANL)
unnamed: CAN-HS1.2, JP-CAN-HS1.1, U4.7 (CANH)
unnamed: CAN-HS2.1, R6.1, U5.6 (CANL)
unnamed: CAN-HS2.2, JP-CAN-HS2.1, U5.7 (CANH)
unnamed: D1.2 (A), Q1.1 (G), R7.2, R19.2
unnamed: D2.1 (K), L1.1, U8.2 (OUT)
unnamed: D4.2, R11.1
unnamed: D6.3 (BK), R22.1
unnamed: D6.2 (GK), R21.1
unnamed: D6.1 (RK), R20.1
unnamed: ESP_FLASH1.1, U3.35 (TXD0/IO1)
unnamed: ESP_FLASH1.2, U3.34 (RXD0/IO3)
unnamed: J3.2, R11.2
unnamed: JP-CAN-HS1.2, R5.1
unnamed: JP-CAN-HS2.2, R6.2
unnamed: K-LINE1.1, U10.6 (LIN)
unnamed: K-LINE1.2, U11.6 (LIN)
unnamed: Q2.3 (D), R19.1
unnamed: D3.3, D4.3, Q2.1 (G), R10.2
unnamed: STM_FLASH1.3, U1.49 (PA14)
unnamed: C36.1, STM_FLASH1.4, U1.7 (NRST)
unnamed: STM_FLASH1.5, U1.46 (PA13)
unnamed: STM_FLASH2.3, U2.49 (PA14)
unnamed: C35.2, STM_FLASH2.4, U2.7 (NRST)
unnamed: STM_FLASH2.5, U2.46 (PA13)
unnamed: R18.2, U1.60 (BOOT0)
unnamed: U1.16 (PA2), U3.31 (IO19)
unnamed: U1.17 (PA3), U3.30 (IO18)
unnamed: U1.44 (PA11), U6.3 (RXD)
unnamed: U1.45 (PA12), U6.2 (TXD)
unnamed: U1.57 (PB5), U7.3 (RXD)
unnamed: U1.58 (PB6), U7.2 (TXD)
unnamed: R8.1, U1.30 (PB11)
unnamed: R9.1, U1.33 (PB12)
unnamed: R15.1, U1.38 (PC7), U6.5 (~STB)
unnamed: R14.2, U1.39 (PC8), U6.6 (EN)
unnamed: U1.51 (PC10), U2.52 (PC11)
unnamed: U1.52 (PC11), U2.51 (PC10)
unnamed: D3.2, U1.2 (PC13)
unnamed: C41.2, U1.5 (PH0), Y1.1
unnamed: C40.2, U1.6 (PH1), Y1.3
unnamed: C13.2, U1.31 (VCAP_1)
unnamed: C20.2, U1.47 (VCAP_2)
unnamed: C7.1, C25.1, FB1.1, U1.13 (VDDA)
unnamed: R12.2, U2.60 (BOOT0)
unnamed: U2.16 (PA2), U3.28 (IO17)
unnamed: U2.17 (PA3), U3.27 (IO16)
unnamed: U2.44 (PA11), U4.4 (RXD)
unnamed: U2.45 (PA12), U4.1 (TXD)
unnamed: U2.57 (PB5), U5.4 (RXD)
unnamed: U2.58 (PB6), U5.1 (TXD)
unnamed: D3.1, U2.2 (PC13)
unnamed: C42.2, U2.5 (PH0), Y2.1
unnamed: C43.2, U2.6 (PH1), Y2.3
unnamed: C12.2, U2.31 (VCAP_1)
unnamed: C29.2, U2.47 (VCAP_2)
unnamed: C19.1, C28.1, FB2.1, U2.13 (VDDA)
unnamed: R20.2, U3.10 (IO25)
unnamed: R21.2, U3.11 (IO26)
unnamed: R22.2, U3.12 (IO27)
unnamed: D4.1, R13.1, U6.1 (INH)
unnamed: R1.2, U6.8 (RTH)
unnamed: R2.2, U6.9 (RTL)
unnamed: R8.2, U6.4 (~ERR)
unnamed: R3.2, U7.8 (RTH)
unnamed: R4.2, U7.9 (RTL)
unnamed: R9.2, U7.4 (~ERR)
unnamed: U2.38 (PC7), U10.1 (RXD)
unnamed: U2.37 (PC6), U10.4 (TXD)
unnamed: U2.43 (PA10), U11.1 (RXD)
unnamed: U2.42 (PA9), U11.4 (TXD)

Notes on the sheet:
Keepalive LS
Keepalive HS
JP_ALWAYS_ON

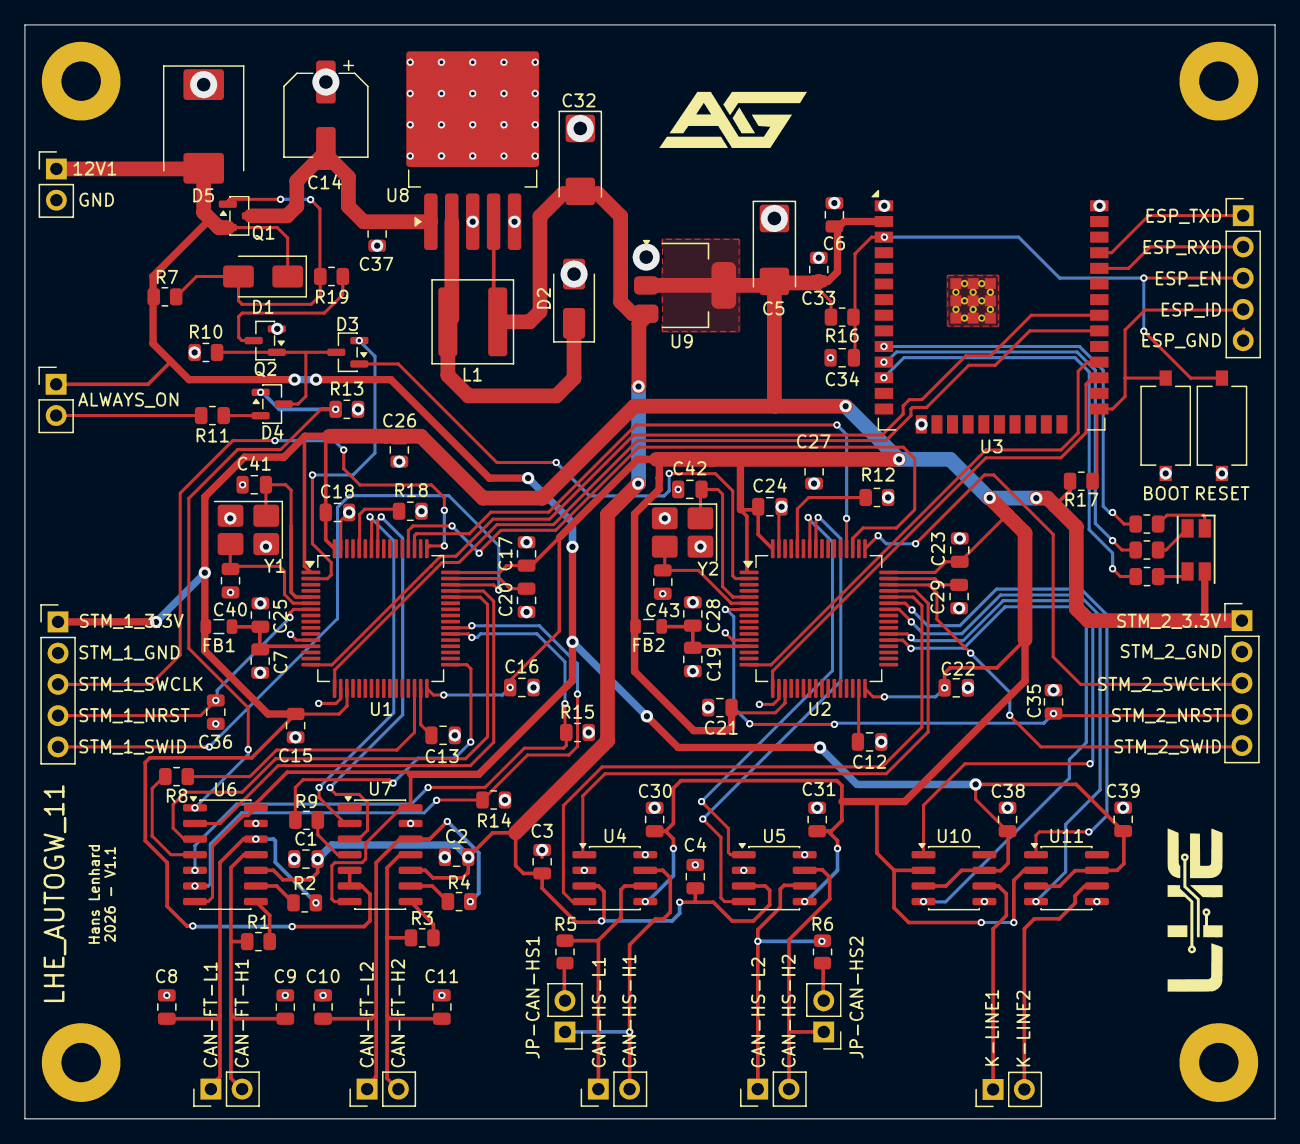
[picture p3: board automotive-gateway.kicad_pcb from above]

Board: 2 copper layers, 101.6 x 88.9 mm, 107 parts (0 on the bottom side), 82 nets.

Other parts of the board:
BOOT: ESP_BOOT; SW_Tactile_SPST_NO_Straight_CK_PTS636Sx25SMTRLFS
RESET: ESP_RESET; SW_Tactile_SPST_NO_Straight_CK_PTS636Sx25SMTRLFS

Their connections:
/ESP_EN: RESET.2; also elsewhere on the board
/ESP_IO: BOOT.1; also elsewhere on the board
/GND: BOOT.2, RESET.1; also elsewhere on the board

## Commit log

2026-07-30 almost done with routing
    [dual-can-gateway.kicad_pcb, dual-can-gateway.kicad_sch]
2026-07-31 done with tracing, time to optimize
    [dual-can-gateway.kicad_pcb, dual-can-gateway.kicad_sch]
2026-07-31 proper pins done
    [dual-can-gateway.kicad_pcb, dual-can-gateway.kicad_sch]
2026-08-01 reworking power input
    [dual-can-gateway.kicad_pcb, dual-can-gateway.kicad_sch]
2026-08-01 print ready
    [dual-can-gateway.kicad_pcb, dual-can-gateway.kicad_sch]
2026-08-02 updated logo
    [dual-can-gateway.kicad_pcb]
2026-08-03 small adjustment
    [dual-can-gateway.kicad_pcb]
2026-08-16 fixed unconnected gnd on stm #1
    [dual-can-gateway.kicad_pcb]
2026-08-19 hopefully fixed auto wake/shutdown
    [dual-can-gateway.kicad_pcb, dual-can-gateway.kicad_sch]
2026-08-30 proper caps added
    [dual-can-gateway.kicad_pcb, dual-can-gateway.kicad_sch]
2026-09-28 we're getting there
    [dual-can-gateway.kicad_pcb, dual-can-gateway.kicad_sch]
2026-09-30 v1.1 almost done, new preview
    [dual-can-gateway.kicad_pcb, dual-can-gateway.kicad_sch]
2026-09-30 added inter mcu communication as well as debug led
    [dual-can-gateway.kicad_pcb, dual-can-gateway.kicad_sch]
2026-10-01 print ready?
    [dual-can-gateway.kicad_pcb]
2026-10-01 added k-line
    [dual-can-gateway.kicad_pcb, dual-can-gateway.kicad_sch]
2026-10-01 Rename project to automotive-gateway and rework README
    - Feature all 3 common ECU communication methods (HS-CAN, FT-CAN, K-Line/LIN)
    - Clarify Normal Mode as active standalone ECU (reading and sending on busses)
    - Clarify MitM Mode for in-line message filtering and payload modification
    - Remove all listen mode references
    - Rename KiCad project and PCB files to automotive-gateway
    - Update remote repository URL and documentation links
    [automotive-gateway.kicad_pcb, automotive-gateway.kicad_sch, dual-can-gateway.kicad_pcb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]
2026-10-01 Add AG (Automotive Gateway) logo footprints and update PCB silkscreen
    - Created logo_ag.kicad_mod (10mm) and size variants: 6mm, 8mm, 12mm, 14mm
    - Created clean vector SVG exports (LOGO_AG.svg, LOGO_AG_12mm.svg)
    - Preserved exact motorsport/OEM styling, 45-degree forward slant, and ribbon stroke weights
    - Updated silkscreen logo on automotive-gateway.kicad_pcb to logo_ag_12mm
    [automotive-gateway.kicad_pcb]
2026-10-01 Refine AG logo with uniform bold stroke on A and matching italic slant
    - Redesigned left leg of A to full 42px uniform thickness matching the rest of the logo
    - Increased forward italic slant (s=0.58) so the A leans dynamically together with the G
    - Cleaned up negative space parallel channels
    - Updated all size variants (6mm, 8mm, 10mm, 12mm, 14mm), SVGs, and PCB silkscreen
    [automotive-gateway.kicad_pcb]
2026-10-01 feat(logo): revise AG logo with clean geometry, uniform stroke weight, and parallel channel separation
    [automotive-gateway.kicad_pcb]
2026-10-01 feat(logo): implement vectorized Concept 3 horizontal racing monogram AG emblem
    [automotive-gateway.kicad_pcb]
2026-10-04 added external clock source
    [automotive-gateway.kicad_pcb, automotive-gateway.kicad_sch]
